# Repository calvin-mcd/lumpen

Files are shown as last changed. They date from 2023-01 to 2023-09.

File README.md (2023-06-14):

# lumpen

lumpen is an entry-level 40% keyboard designed around the [rp2040-zero](https://www.waveshare.com/rp2040-zero.htm) micro controller from waveshare.
This is a plateless build with a pcb with flex cuts for some bounce and a simple backplate.
The keyboard sports a uniform stagger layout with big bar or split bar options for the bottom row. 
It also supports one rortary encoder at the bottom left and has a rgb breakout (see RGB for details!).

The design takes cues and inspiration from amazing keyboards such as trash man\#6005’s [Coriander](https://trashman.wiki/cases/coriander), rain\#3950's [hubris](https://github.com/rainkeebs/hubris-mv-case) and matthewdias' [model-v](https://github.com/matthewdias/model-v).

## Layout

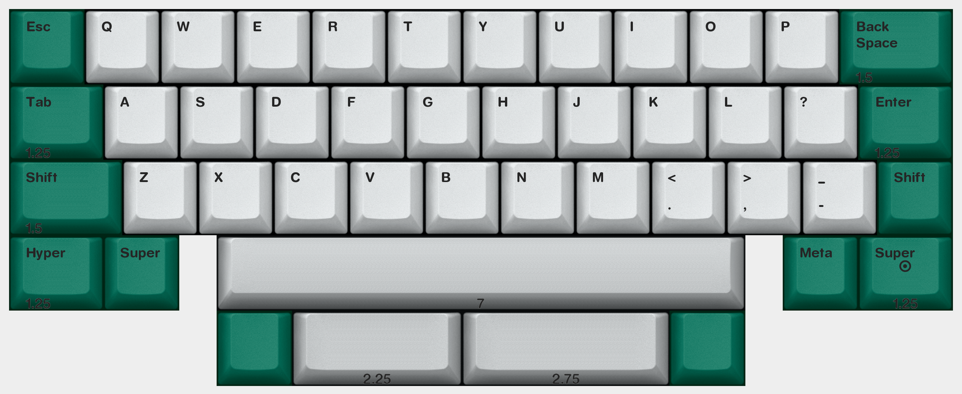
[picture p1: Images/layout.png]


[Link](http://www.keyboard-layout-editor.com/#/gists/c5cd2165b0487d952150a8d600422438)

## Build Guide

*Step 1*

When building the keyboard make sure that you solder the switch on top of the micro controller before installing the controller! First solder the controller headers in place, make sure to cut them as flush as possible. Then solder the switch. Afterwards solder the controller.

Version 1.0 had some small interferences between that switch and the pins of the controller. Effort has been made to minimise that with version 1.1 but it has not been tested. In case of interference I recommend to cut part of the bottom housing of the switch. That worked well on version 1.0. (see pictures below)

*Step 2*

Solder the diodes of your choice. The pcb supports both through hole and smd diodes. Install stabilisers and solder the switches.

*Step 3*

Put standoffs on the pcb. Screw backplate onto the board.

The board uses m2 screwholes and works well with 10mm standoffs. For a smoother experience I recommend using a o-ring each between standoff and pcb (see pictures below).

*RGB*

Because this board uses a rp2040, you will need to use a logic shifter to utilise the rgb breakout. Something like [this](https://learn.sparkfun.com/tutorials/retired---using-the-logic-level-converter) or [this](https://learn.sparkfun.com/tutorials/bi-directional-logic-level-converter-hookup-guide) for example. Or you could try this [hack](https://hackaday.com/2017/01/20/cheating-at-5v-ws2812-control-to-use-a-3-3v-data-line/).

There are two firmwares are provided. I recommend the firmware that is using the onboard single led of the rp2040-zero. The second firmware is supposed to support the rgb strip with the above mentioned caveat.

## Pictures

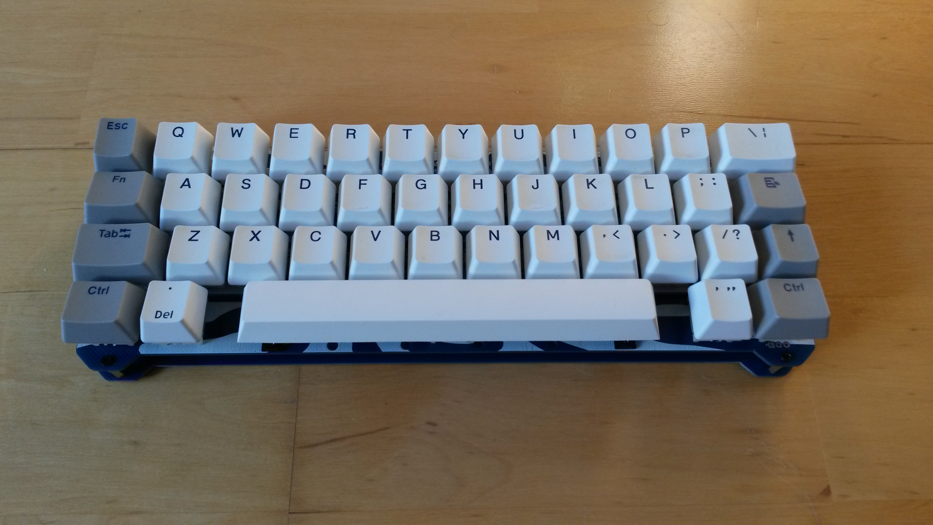
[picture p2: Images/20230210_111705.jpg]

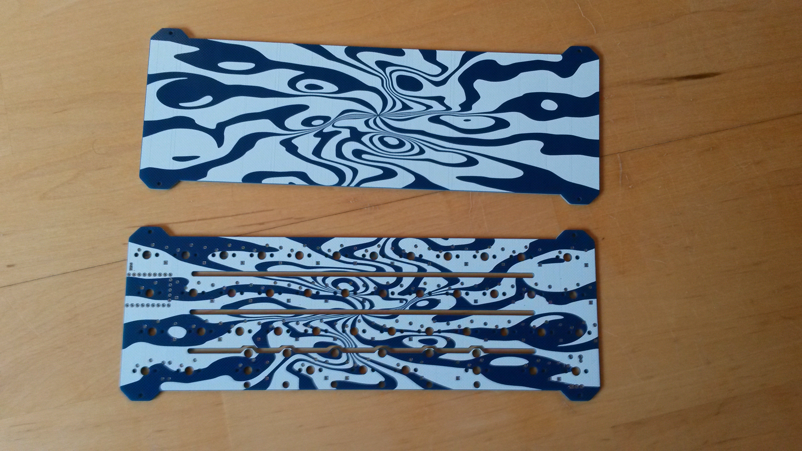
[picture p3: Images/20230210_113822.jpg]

Soyo#3925's build:
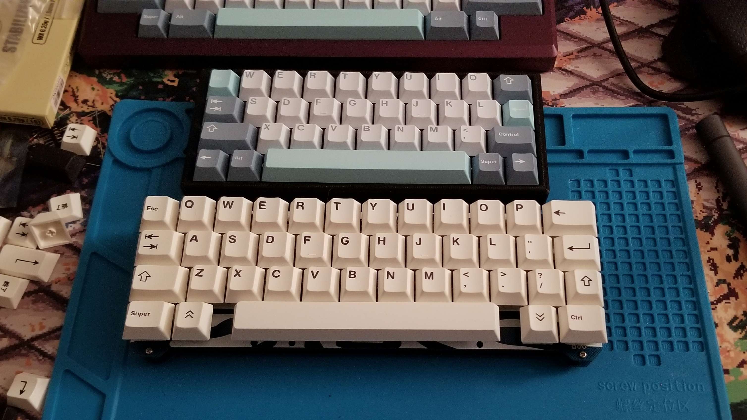
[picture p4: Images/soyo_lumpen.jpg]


Gerber Renders
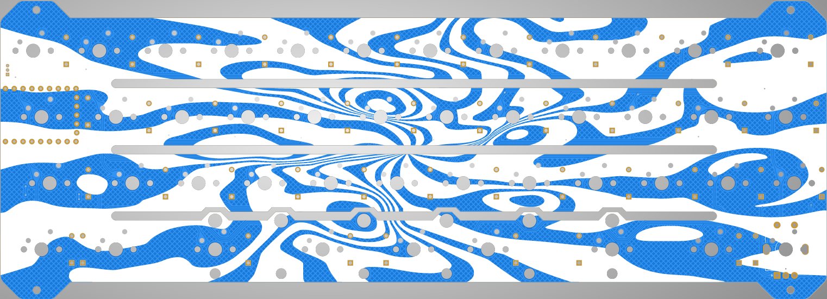
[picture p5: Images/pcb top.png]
  
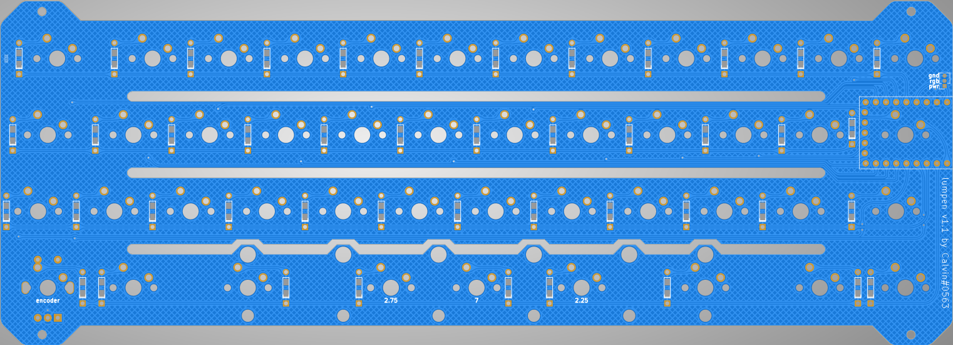
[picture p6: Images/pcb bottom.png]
  
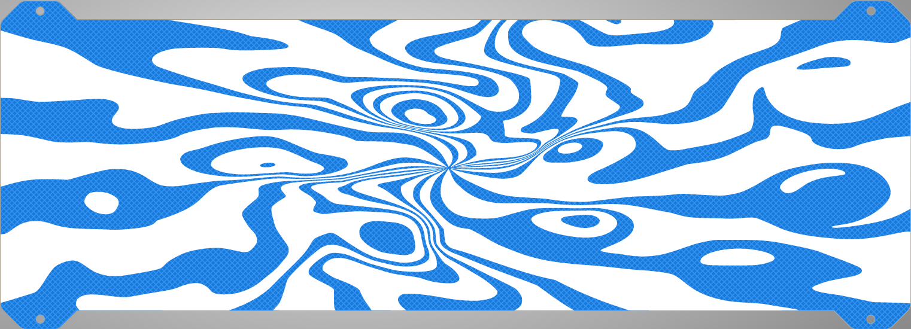
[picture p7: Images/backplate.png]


Picture of the switch sitting on top of the controler
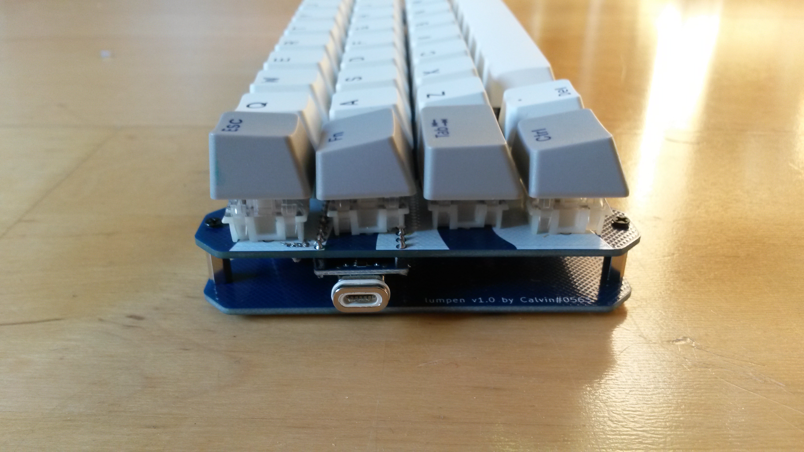
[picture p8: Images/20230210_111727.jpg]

Picture of the oring between standoffs and pcb
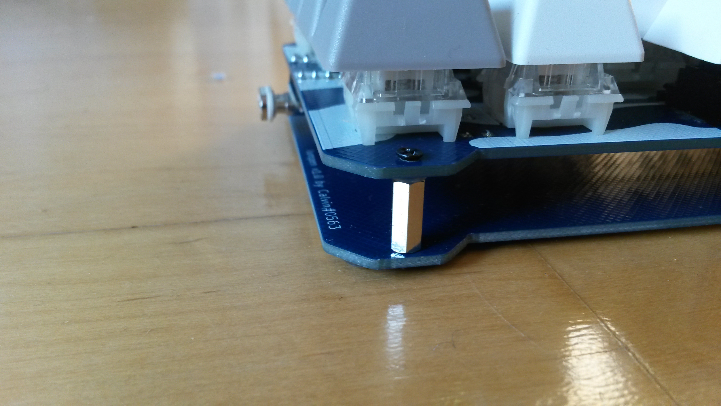
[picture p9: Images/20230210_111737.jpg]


## Disclaimer

This PCB has been fully tested and is confirmed to work. However, no-one involved in this project is responsible for any usage issues that may arise. Order at your own risk. Feel free to edit, modify and otherwise utilise these files.

## License

This project is released under the GPL v3 License. Please refer to the LICENCE file.

## Credits

As always big thanks to the many people who helped me and inspired this board!

Any questions, contact Calvin\#0563 on Discord.

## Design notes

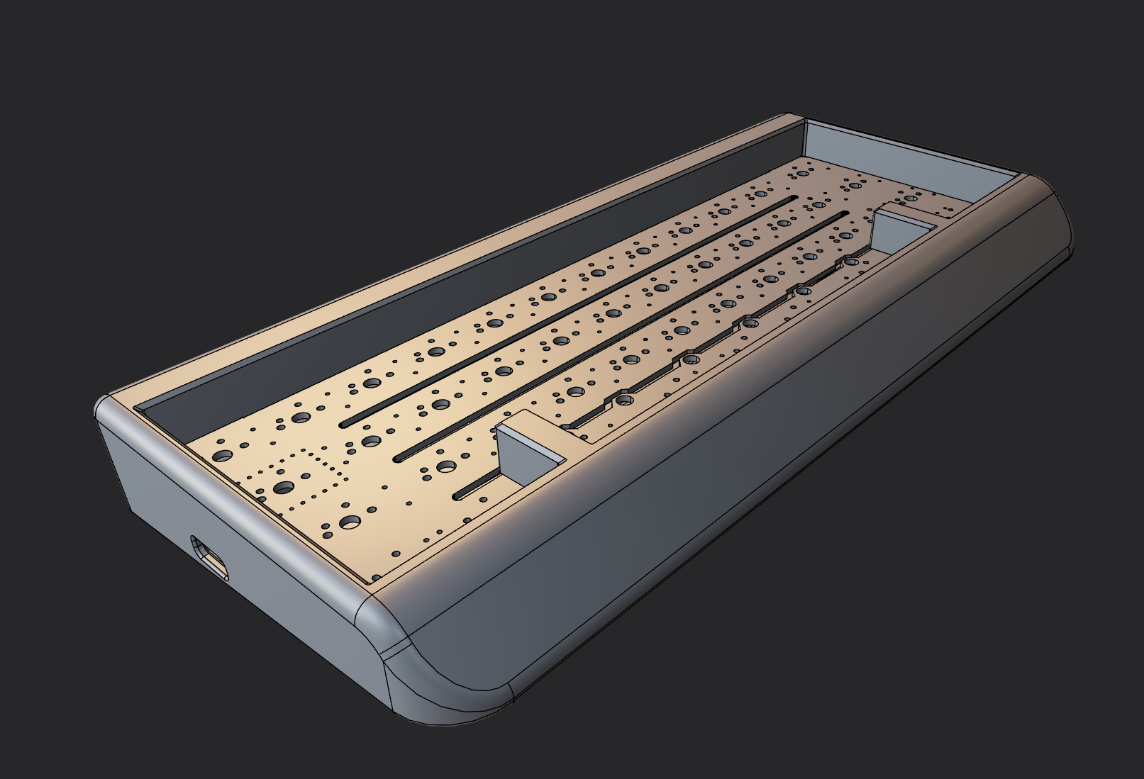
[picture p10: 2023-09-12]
Images/image.png

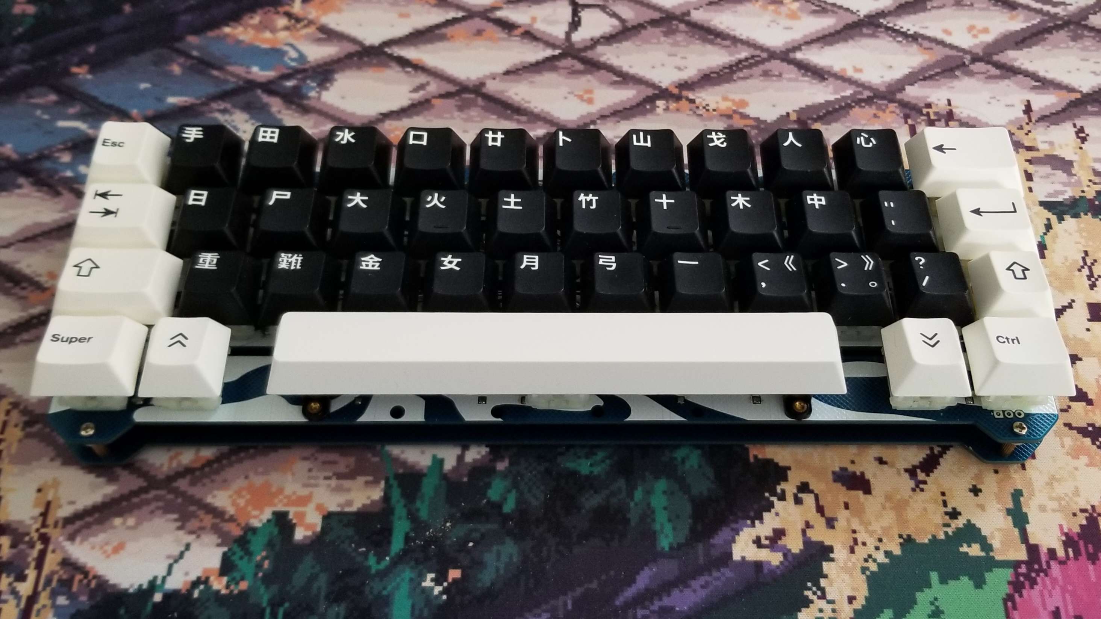
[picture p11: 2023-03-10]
Images/soyo_lumpen1.jpg

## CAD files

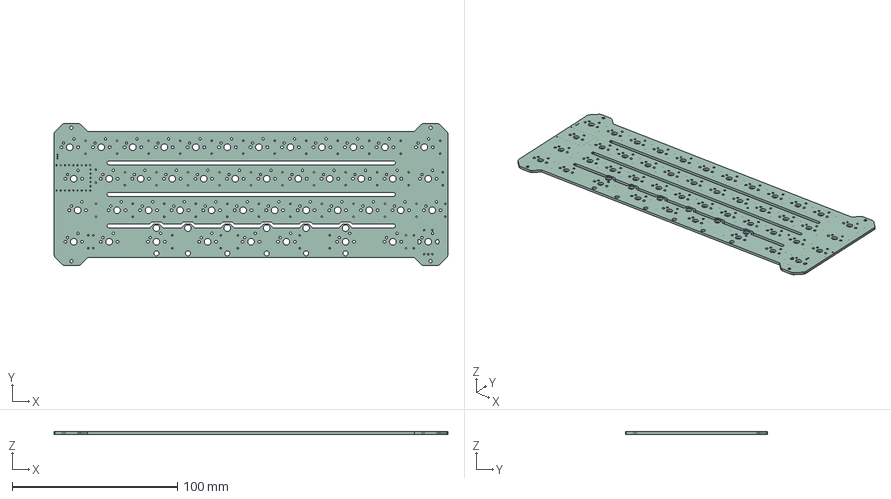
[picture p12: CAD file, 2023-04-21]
Project/lumpen.step
238.1 x 86.1 x 1.60 mm

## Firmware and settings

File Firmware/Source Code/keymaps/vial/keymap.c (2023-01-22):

/*
Copyright 2022 

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
You should have received a copy of the GNU General Public License
along with this program.  If not, see <http://www.gnu.org/licenses/>.
*/

#include QMK_KEYBOARD_H

const uint16_t PROGMEM keymaps[][MATRIX_ROWS][MATRIX_COLS] = {

	[0] = LAYOUT(
		KC_ESC,	 KC_Q,    KC_W,    KC_E,    KC_R,    KC_T,    KC_Y,    KC_U,    KC_I,    KC_O,    KC_P,		KC_BSPC,   
		KC_TAB,	 KC_A,    KC_S,    KC_D,    KC_F,    KC_G,    KC_H,    KC_J,    KC_K,    KC_L,	  KC_QUES,  KC_ENT, 
		KC_LSFT, KC_Z,    KC_X,    KC_C,    KC_V,    KC_B,    KC_N,    KC_M,    KC_COMM, KC_DOT,  KC_SLASH,	KC_RSFT,
		KC_LCTRL, KC_LALT,							KC_SPACE,									  KC_RALT,	KC_RCTRL
	),

	[1] = LAYOUT(
		KC_TRNS,	 KC_TRNS,    KC_TRNS,    KC_TRNS,    KC_TRNS,    KC_TRNS,    KC_TRNS,    KC_TRNS,    KC_TRNS,    KC_TRNS,		KC_TRNS,		KC_TRNS,   
		KC_TRNS,	 KC_TRNS,    KC_TRNS,    KC_TRNS,    KC_TRNS,    KC_TRNS,    KC_TRNS,    KC_TRNS,    KC_TRNS,    KC_TRNS,		KC_TRNS,		KC_TRNS, 
		KC_TRNS,	 KC_TRNS,    KC_TRNS,    KC_TRNS,    KC_TRNS,    KC_TRNS,    KC_TRNS,    KC_TRNS,    KC_TRNS,	 KC_TRNS,		KC_TRNS,		KC_TRNS,
		KC_TRNS,	 KC_TRNS,									     KC_TRNS,												        KC_TRNS,		KC_TRNS
	),

	[2] = LAYOUT(
		KC_TRNS,	 KC_TRNS,    KC_TRNS,    KC_TRNS,    KC_TRNS,    KC_TRNS,    KC_TRNS,    KC_TRNS,    KC_TRNS,    KC_TRNS,		KC_TRNS,		KC_TRNS,   
		KC_TRNS,	 KC_TRNS,    KC_TRNS,    KC_TRNS,    KC_TRNS,    KC_TRNS,    KC_TRNS,    KC_TRNS,    KC_TRNS,    KC_TRNS,		KC_TRNS,		KC_TRNS, 
		KC_TRNS,	 KC_TRNS,    KC_TRNS,    KC_TRNS,    KC_TRNS,    KC_TRNS,    KC_TRNS,    KC_TRNS,    KC_TRNS,	 KC_TRNS,		KC_TRNS,		KC_TRNS,
		KC_TRNS,	 KC_TRNS,									     KC_TRNS,												        KC_TRNS,		KC_TRNS
	),

	[3] = LAYOUT(
		KC_TRNS,	 KC_TRNS,    KC_TRNS,    KC_TRNS,    KC_TRNS,    KC_TRNS,    KC_TRNS,    KC_TRNS,    KC_TRNS,    KC_TRNS,		KC_TRNS,		KC_TRNS,   
		KC_TRNS,	 KC_TRNS,    KC_TRNS,    KC_TRNS,    KC_TRNS,    KC_TRNS,    KC_TRNS,    KC_TRNS,    KC_TRNS,    KC_TRNS,		KC_TRNS,		KC_TRNS, 
		KC_TRNS,	 KC_TRNS,    KC_TRNS,    KC_TRNS,    KC_TRNS,    KC_TRNS,    KC_TRNS,    KC_TRNS,    KC_TRNS,	 KC_TRNS,		KC_TRNS,		KC_TRNS,
		KC_TRNS,	 KC_TRNS,									     KC_TRNS,												        KC_TRNS,		KC_TRNS
	),

	[4] = LAYOUT(
        KC_TRNS,	 KC_TRNS,    KC_TRNS,    KC_TRNS,    KC_TRNS,    KC_TRNS,    KC_TRNS,    KC_TRNS,    KC_TRNS,    KC_TRNS,		KC_TRNS,		KC_TRNS,   
		KC_TRNS,	 KC_TRNS,    KC_TRNS,    KC_TRNS,    KC_TRNS,    KC_TRNS,    KC_TRNS,    KC_TRNS,    KC_TRNS,    KC_TRNS,		KC_TRNS,		KC_TRNS, 
		KC_TRNS,	 KC_TRNS,    KC_TRNS,    KC_TRNS,    KC_TRNS,    KC_TRNS,    KC_TRNS,    KC_TRNS,    KC_TRNS,	 KC_TRNS,		KC_TRNS,		KC_TRNS,
		KC_TRNS,	 KC_TRNS,									     KC_TRNS,												        KC_TRNS,		KC_TRNS
	)
};

/* Encoder */ 
const uint16_t PROGMEM encoder_map[][NUM_ENCODERS][2] = {
    [0] = { ENCODER_CCW_CW(KC_NO, KC_NO) },
    [1] = { ENCODER_CCW_CW(KC_NO, KC_NO) },
    [2] = { ENCODER_CCW_CW(KC_NO, KC_NO) },
    [3] = { ENCODER_CCW_CW(KC_NO, KC_NO) },
    [4] = { ENCODER_CCW_CW(KC_NO, KC_NO) }
};

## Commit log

2023-01-07 moved project
    [Premium lumpen.kicad_sch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]
2023-01-11 changed zone filling on lumpen, worked on premium
    [Premium lumpen.kicad_sch]
2023-01-12 premium 3 flex cut matrix routed
    [Premium lumpen.kicad_sch]
2023-01-13 auto save
    [Premium lumpen.kicad_sch]
2023-01-15 premium work
    [Premium lumpen.kicad_sch]
2023-01-15 moved premium to on-hold
    [Premium lumpen.kicad_sch]
2023-01-21 cleaned up project
    [lumpen switchplate.kicad_pcb]
2023-01-22 adding labels on pcb, fresh production files, adding firmware folder
    [lumpen-B_Mask.gbr, lumpen-B_Paste.gbr, lumpen-B_Silkscreen.gbr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]
2023-01-22 changed rgb breakout, for easier use
    [lumpen-B_Mask.gbr, lumpen-B_Paste.gbr, lumpen-B_Silkscreen.gbr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]
2023-02-08 lumpen v1.1
    changed the placement of microcontroller ever so slightly for hopefully better fitment for switch
    added rotary legs for better support of lowprofile non click rotaries
    [lumpen.kicad_sch]
2023-02-09 readme & images
    [lumpen-B_Mask.gbr, lumpen-B_Paste.gbr, lumpen-B_Silkscreen.gbr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]
2023-02-09 added 1 led vial
    need to add newest source code before publishing
2023-02-10 created project folder for kicad files
    [lumpen.kicad_sch]
2023-02-24 readme update
    [lumpen.kicad_sch]
2023-04-21 backup, pcb step file
    [lumpen.step]
2023-04-24 cleared interference issues
    [lumpen-B_Mask.gbr, lumpen-B_Paste.gbr, lumpen-B_Silkscreen.gbr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]
2023-09-12 added wip case renders

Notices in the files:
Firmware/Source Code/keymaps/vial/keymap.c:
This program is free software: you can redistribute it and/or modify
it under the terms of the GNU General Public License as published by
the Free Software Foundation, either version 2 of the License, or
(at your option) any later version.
